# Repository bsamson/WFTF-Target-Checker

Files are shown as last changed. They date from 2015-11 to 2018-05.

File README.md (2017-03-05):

# WFTF-Target-Checker
World Field Target Federation target checking device, plans source code and instructions for manufacture and assembly.

## Printing
There are 8 parts that need to be printed, the STL files can be found in the STL directory.
All dimentions are in mm and the parts are oriented so that no support structures are required.

For best results the parts should be printed in PLA/PHA filament (ColorFabb recommended)
The Left and Right hand Cylinder parts may be prone to some curling on the edges and as a result it is recommended that they are printed individually.

### Suggested printer settings
- Layer height : **0.12 mm**
- Nozzle size : **0.4 mm**
- Print speed : **50 mm/s**
- Fill Density : **25%**

## Assembly Instructions

### Non-Printed parts required :
- 4mm Steel Bar 140mm long
- M3 Nyloc nuts X 8
- M3 x 30mm Cap Head Bolts X 8
- Small spring - 10mm x 5mm
- Main spring 
  - 12.7mm OD
  - 1.25mm Wire
  - Stainless steel
  - 140mm long
  - rated at around 4Nm per cm of compression
  
Note:  This is the spring supplier on eBay that I have used to make the official WFTF checkers :
http://www.ebay.co.uk/itm/12-7mm-OD-13mm-Stainless-Carbon-steel-Compression-spring-up-to-600mm-long-/231995371162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

### Assembly diagrams :
- [Step 1.pdf](Assembly Instructions/Step 1.PDF)
- [Step 2.pdf](Assembly Instructions/Step 2.PDF)
- [Step 3.pdf](Assembly Instructions/Step 3.PDF)
- [Step 4.pdf](Assembly Instructions/Step 4.PDF)
- [Step 5.pdf](Assembly Instructions/Step 5.PDF)
- [Step 6.pdf](Assembly Instructions/Step 6.PDF)

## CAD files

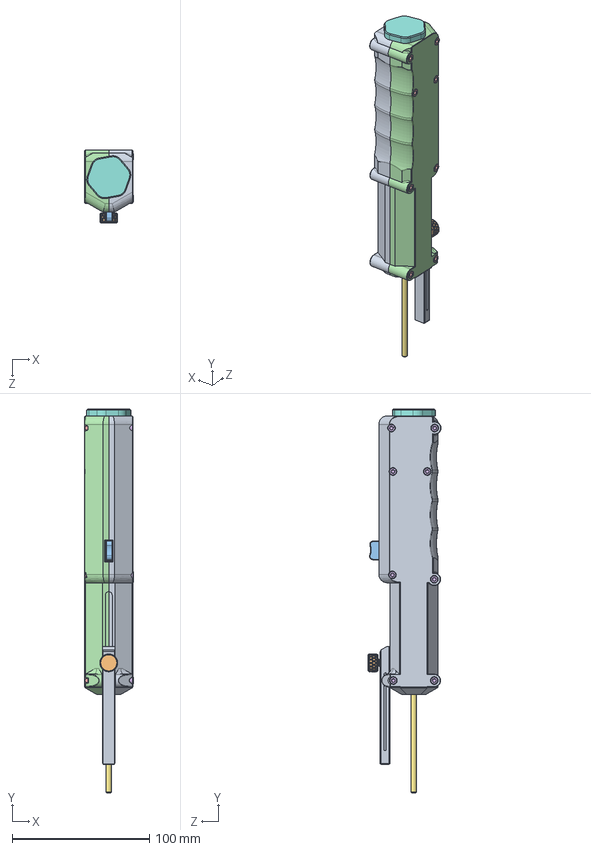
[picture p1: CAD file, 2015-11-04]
Solidworks/Assemblies/Full Assembly.SLDASM
35.3 x 279.8 x 53.2 mm
Cylinder Left Side
Sear Pin
Trigger Sear
Sear return spring
Piston Body
Piston End
Probe
Cylinder End
Depth Gauge
Depth Gauge Screw
Main Spring
Cylinder Right Side
prevailing torque hex nut_am x 8
socket head cap screw_am x 8

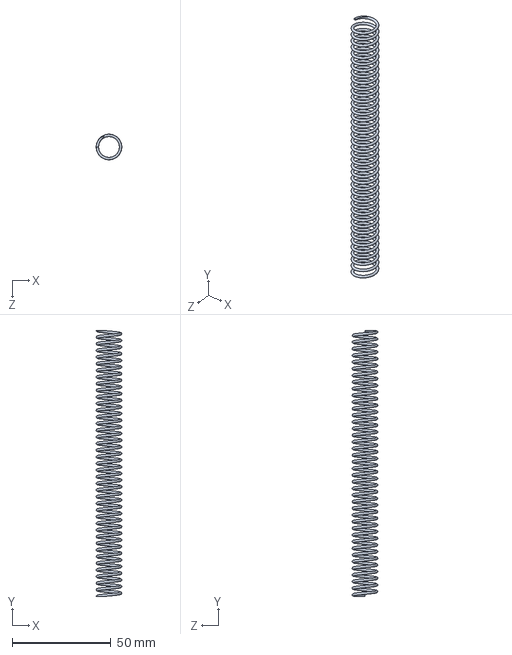
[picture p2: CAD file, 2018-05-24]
Solidworks/Parts/Main Spring.SLDPRT
13.0 x 134.4 x 13.0 mm

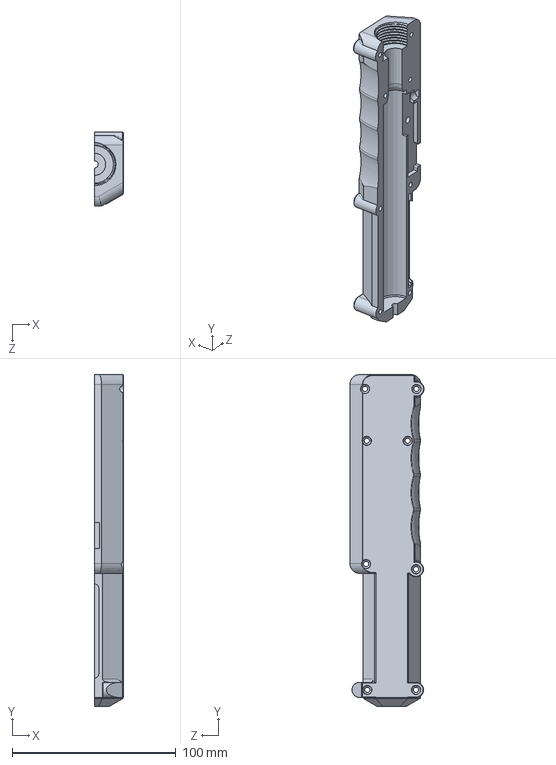
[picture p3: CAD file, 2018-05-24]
Solidworks/Parts/Cylinder Left Side.sldprt
17.5 x 203.0 x 45.3 mm

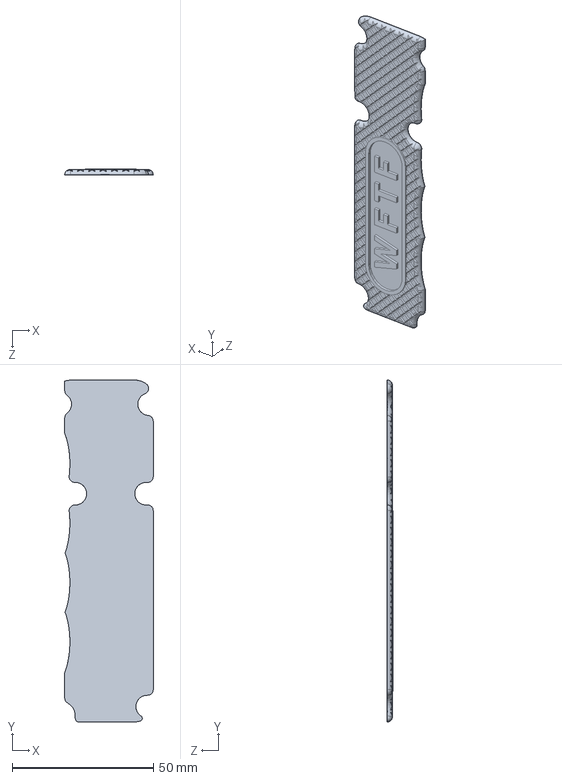
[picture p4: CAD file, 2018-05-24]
Solidworks/Parts/Extras/WFTF Handle LH.sldprt
31.4 x 121.1 x 2.30 mm

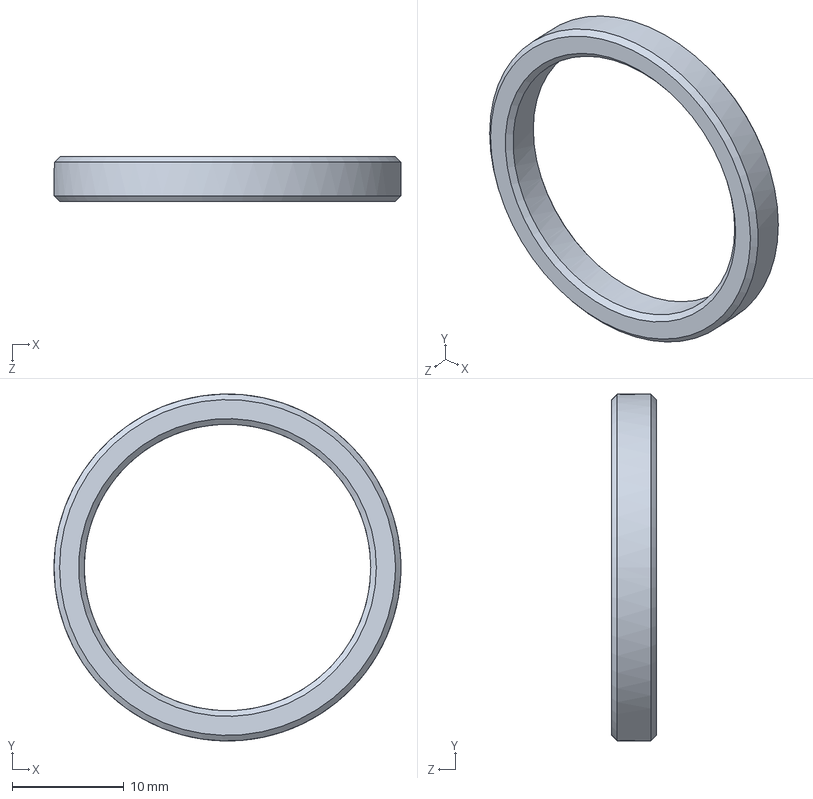
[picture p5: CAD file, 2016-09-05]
Solidworks/Parts/Power Spacers/2_6mm Spacer.SLDPRT
31.0 x 31.0 x 4.00 mm

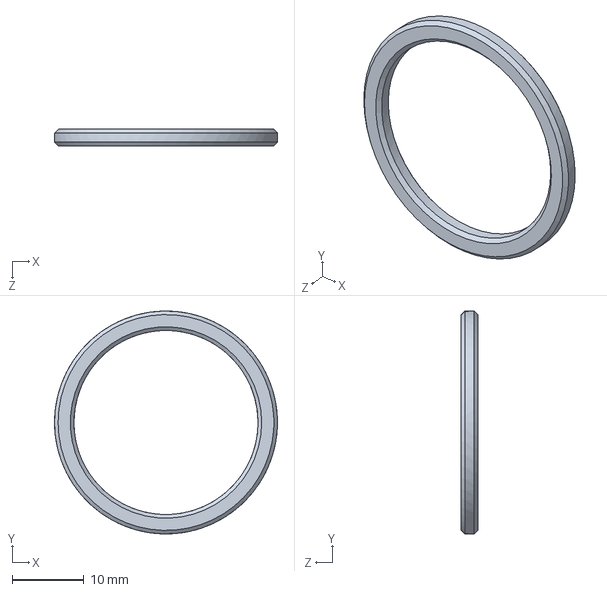
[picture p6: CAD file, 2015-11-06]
Solidworks/Parts/Power Spacers/2_3mm Spacer.SLDPRT
31.0 x 31.0 x 2.30 mm

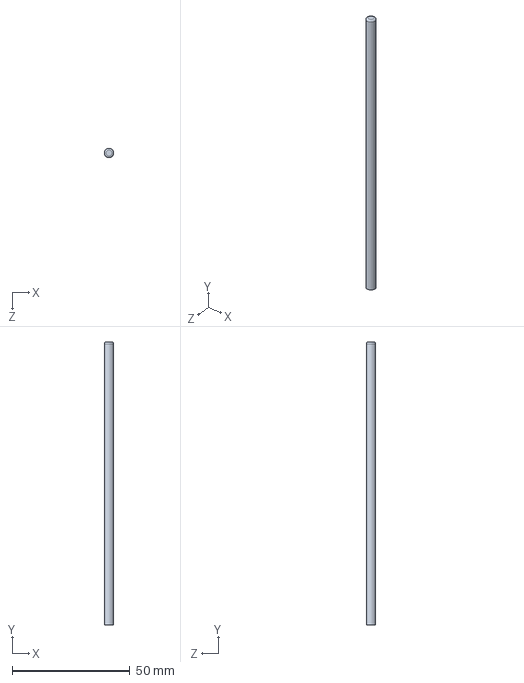
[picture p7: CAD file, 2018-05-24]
Solidworks/Parts/Probe.SLDPRT
4.00 x 120.0 x 4.00 mm

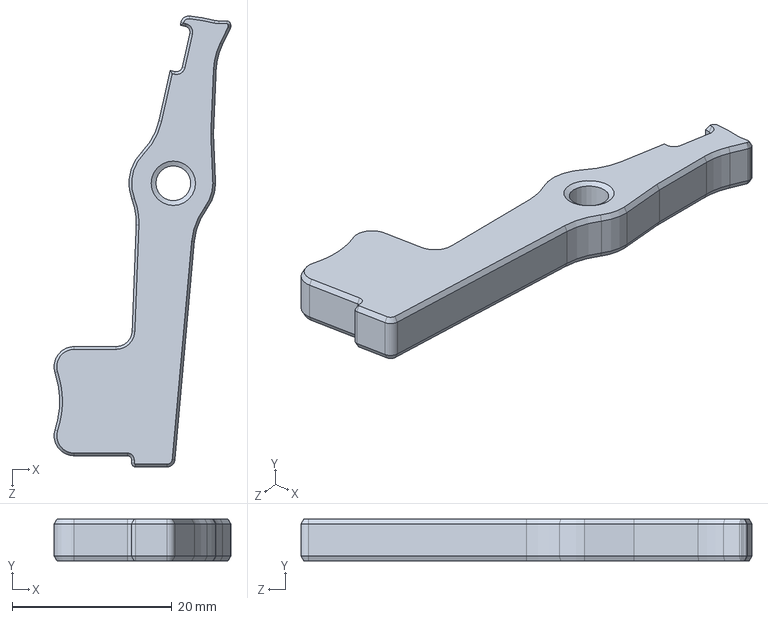
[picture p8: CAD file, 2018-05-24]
Solidworks/Parts/Trigger Sear.SLDPRT
22.1 x 5.25 x 56.4 mm

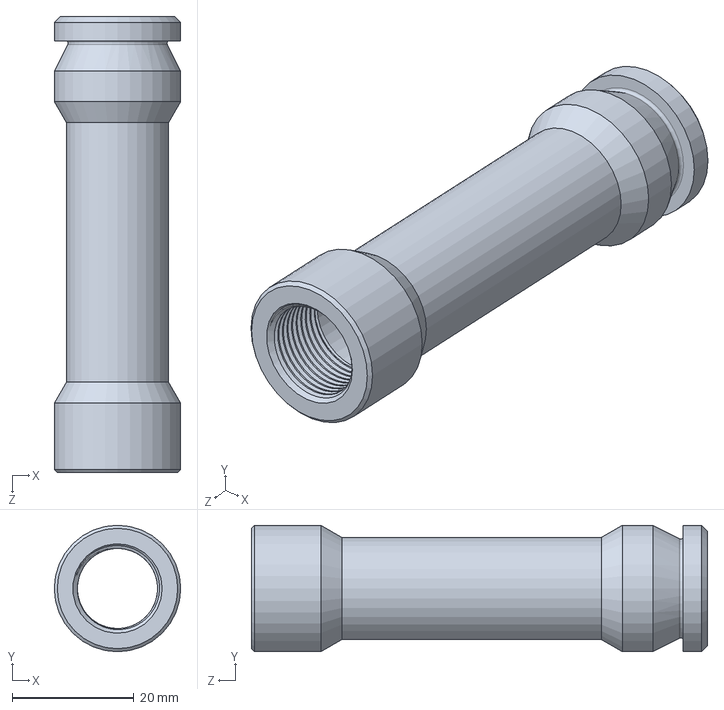
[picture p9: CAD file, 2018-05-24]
Solidworks/Parts/Piston Body.SLDPRT
20.8 x 20.8 x 75.0 mm

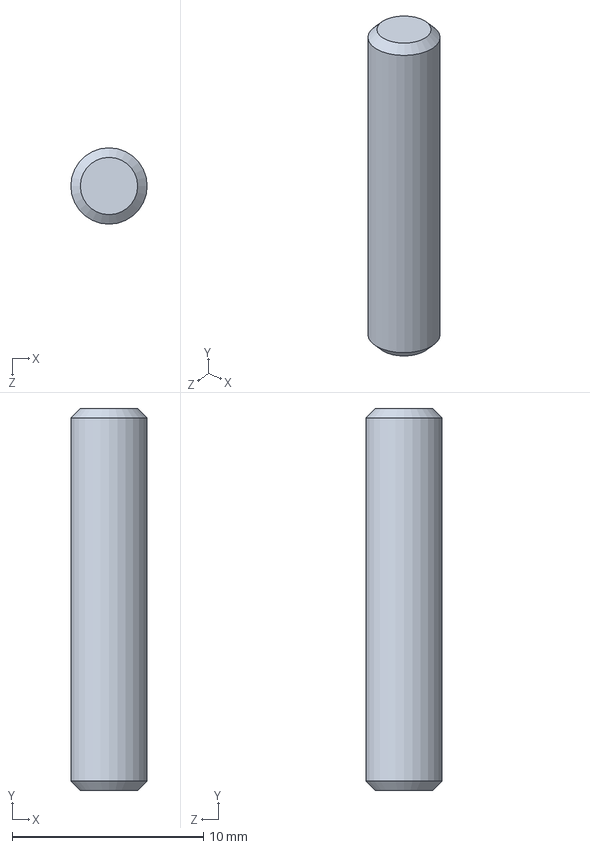
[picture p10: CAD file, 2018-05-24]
Solidworks/Parts/Sear Pin.SLDPRT
4.00 x 20.0 x 4.00 mm

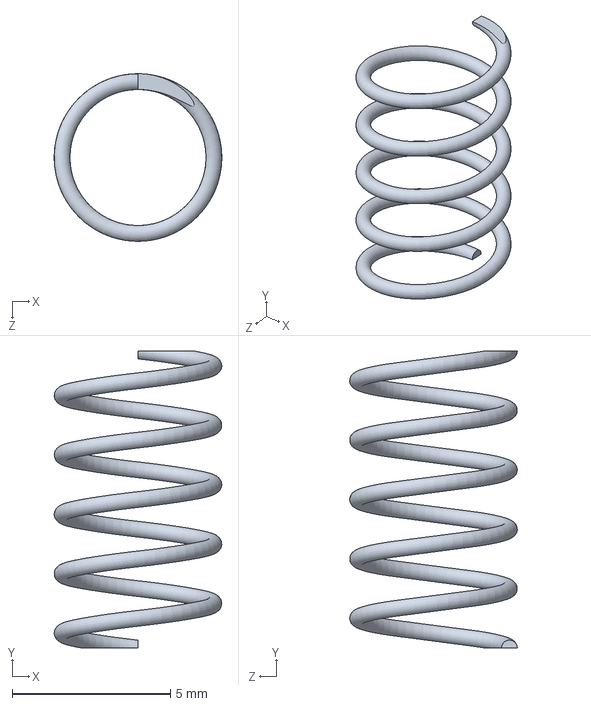
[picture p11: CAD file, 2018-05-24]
Solidworks/Parts/Sear return spring.SLDPRT
5.30 x 9.39 x 5.30 mm

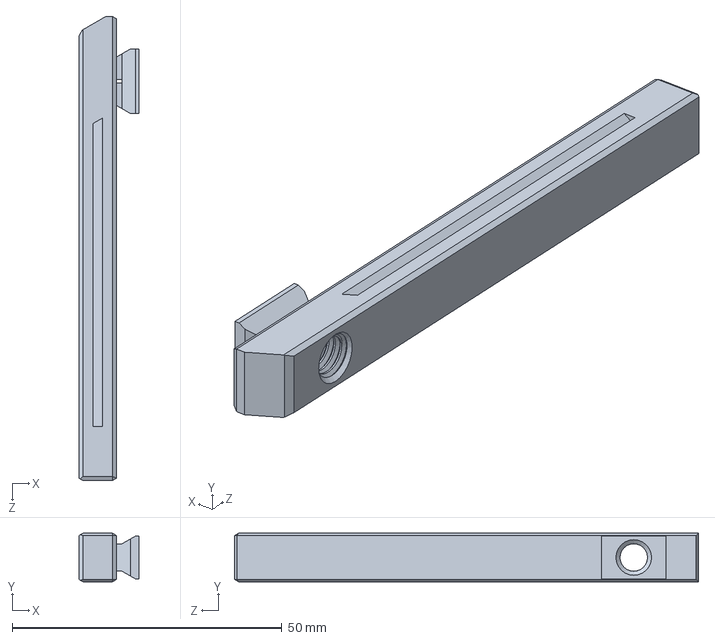
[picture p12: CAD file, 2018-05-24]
Solidworks/Parts/Depth Gauge.SLDPRT
11.2 x 9.00 x 86.0 mm

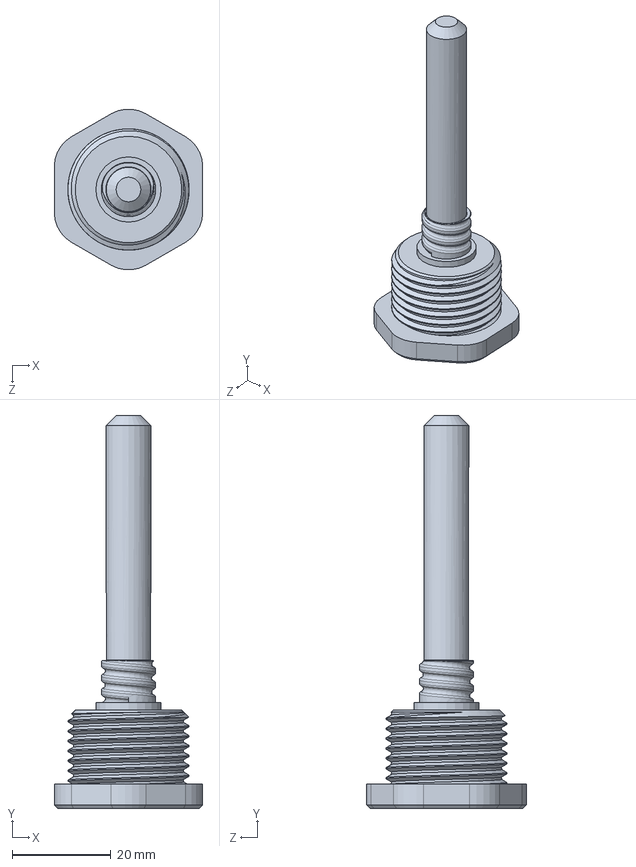
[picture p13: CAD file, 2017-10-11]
Solidworks/Parts/Cylinder End.SLDPRT
30.0 x 79.4 x 32.4 mm

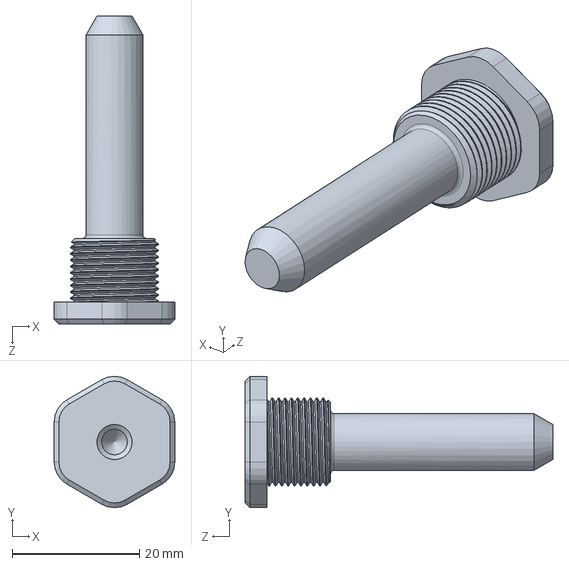
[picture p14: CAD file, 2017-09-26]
Solidworks/Parts/Piston End.SLDPRT
19.0 x 20.7 x 48.5 mm

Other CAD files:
STL/Power Spacers/4mm Spacer.STL
Solidworks/Parts/Extras/WFTF Handle RH.sldprt
Solidworks/Parts/Cylinder Right Side.sldprt
Solidworks/Parts/Cylinder.SLDPRT
STL/Cylinder End.STL
STL/Cylinder Left Side.STL
STL/Cylinder Right Side.STL
STL/Depth Gauge Screw.STL
STL/Depth Gauge.STL
STL/Extras/WFTF Handle LH.STL
STL/Extras/WFTF Handle RH.STL
STL/Piston Body.STL
STL/Piston End.STL
STL/Power Spacers/2_3mm Spacer.STL
STL/Power Spacers/2_6mm Spacer.STL
STL/Trigger Sear.STL
Solidworks/Drawings/Assembly Instruction Drawings/Step 1.SLDDRW
Solidworks/Drawings/Assembly Instruction Drawings/Step 2.SLDDRW
Solidworks/Drawings/Assembly Instruction Drawings/Step 3.SLDDRW
Solidworks/Drawings/Assembly Instruction Drawings/Step 4.SLDDRW
Solidworks/Drawings/Assembly Instruction Drawings/Step 5.SLDDRW
Solidworks/Drawings/Assembly Instruction Drawings/Step 6.SLDDRW
Solidworks/Drawings/Full Assembly.SLDDRW
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

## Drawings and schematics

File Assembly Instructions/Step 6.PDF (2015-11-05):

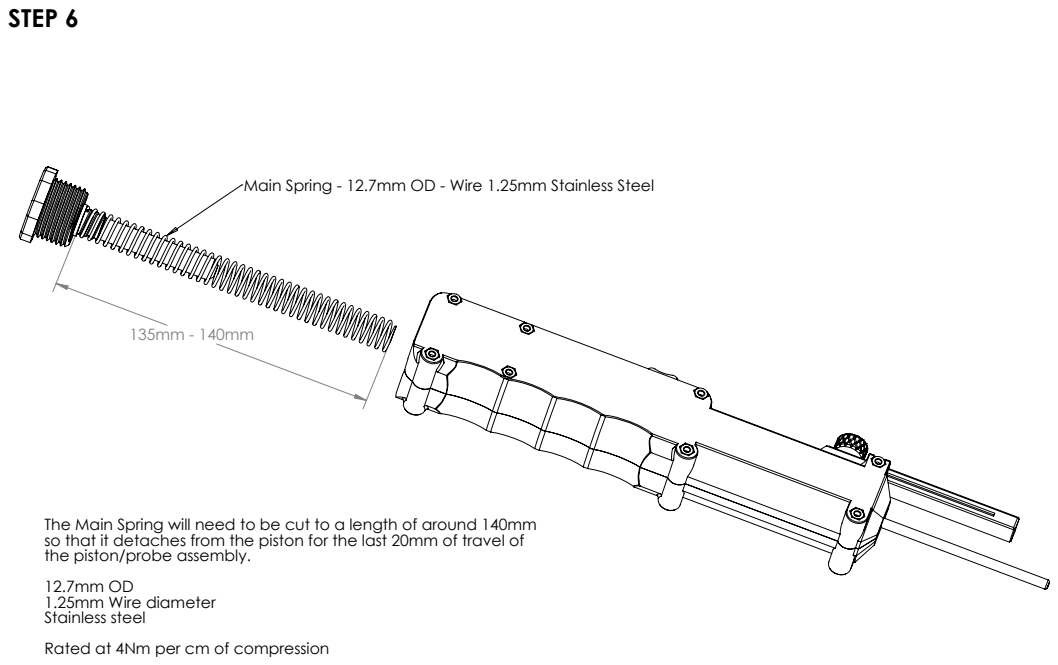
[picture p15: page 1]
STEP 6

Main Spring - 12.7mm OD - Wire 1.25mm Stainless Steel

The Main Spring will need to be cut to a length of around 140mm
so that it detaches from the piston for the last 20mm of travel of
the piston/probe assembly.
1.25mm Wire diameter
Stainless steel
Rated at 4Nm per cm of compression

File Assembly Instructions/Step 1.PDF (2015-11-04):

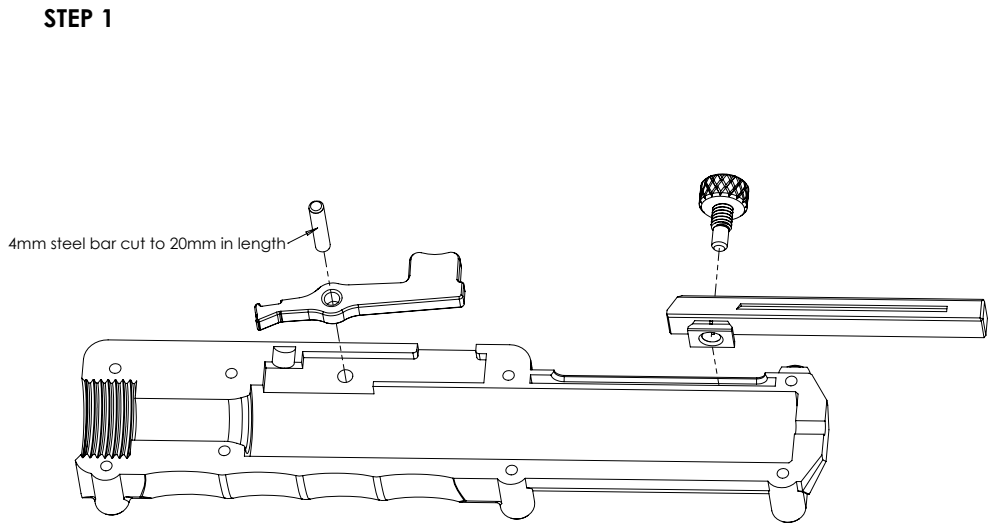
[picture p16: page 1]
STEP 1

4mm steel bar cut to 20mm in length

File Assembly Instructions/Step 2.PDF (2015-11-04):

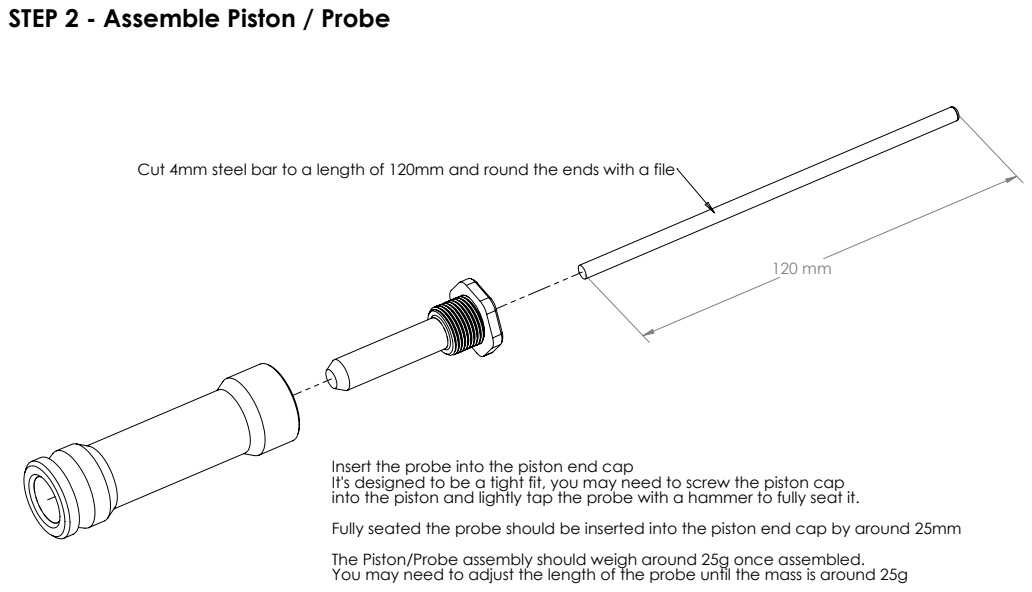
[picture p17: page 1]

STEP 2 - Assemble Piston / Probe

Cut 4mm steel bar to a length of 120mm and round the ends with a file

Insert the probe into the piston end cap
It's designed to be a tight fit, you may need to screw the piston cap
into the piston and lightly tap the probe with a hammer to fully seat it.
Fully seated the probe should be inserted into the piston end cap by around 25mm
The Piston/Probe assembly should weigh around 25g once assembled.
You may need to adjust the length of the probe until the mass is around 25g

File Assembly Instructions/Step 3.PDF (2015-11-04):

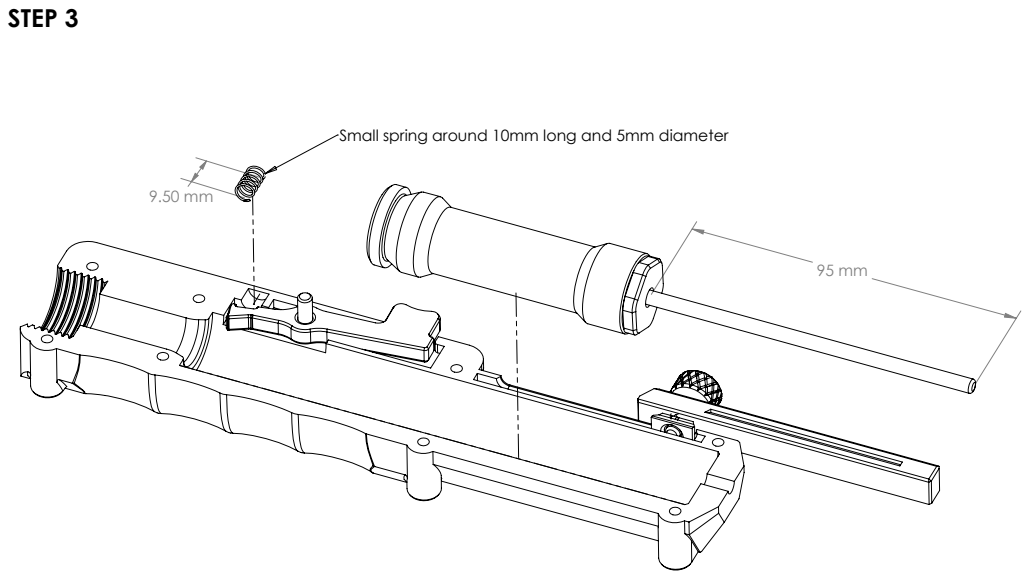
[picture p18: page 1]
STEP 3

Small spring around 10mm long and 5mm diameter

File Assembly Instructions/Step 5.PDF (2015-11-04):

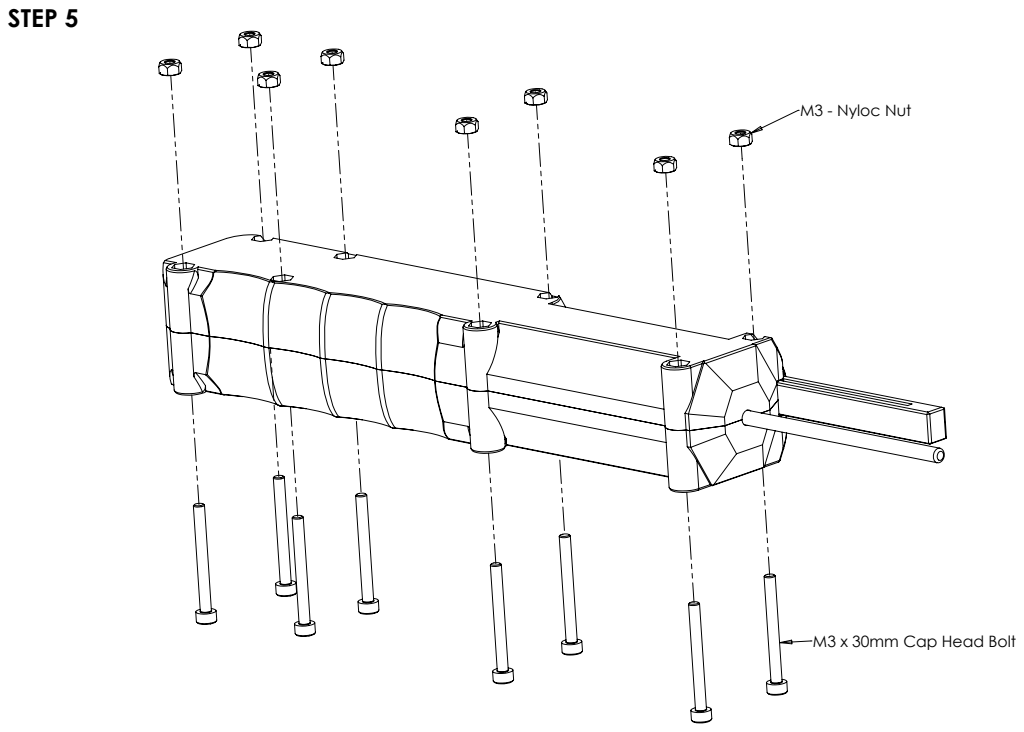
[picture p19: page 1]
M3 - Nyloc Nut; STEP 5

M3 x 30mm Cap Head Bolt

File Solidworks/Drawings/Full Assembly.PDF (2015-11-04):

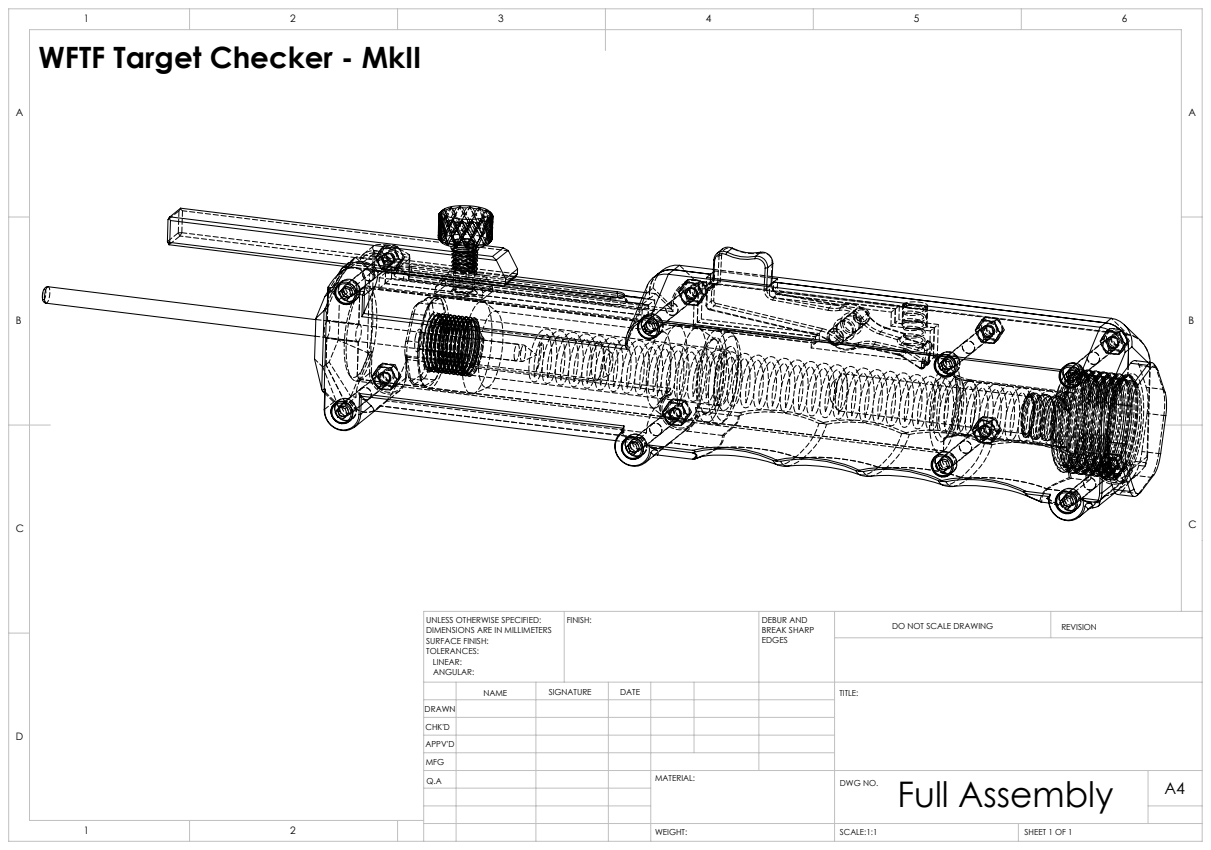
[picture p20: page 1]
FINISH:; DEBUR AND; BREAK SHARP; DO NOT SCALE DRAWING; REVISION; SCALE:1:1; SHEET 1 OF 1

WFTF Target Checker - MkII

UNLESS OTHERWISE SPECIFIED:
DIMENSIONS ARE IN MILLIMETERS
SURFACE FINISH:
TOLERANCES:
LINEAR:
ANGULAR:

NAME | SIGNATURE | DATE | | | | TITLE:

DRAWN
CHK'D
APPV'D
MFG
Q.A | | | | MATERIAL: | Full Assembly DWG NO. | A4

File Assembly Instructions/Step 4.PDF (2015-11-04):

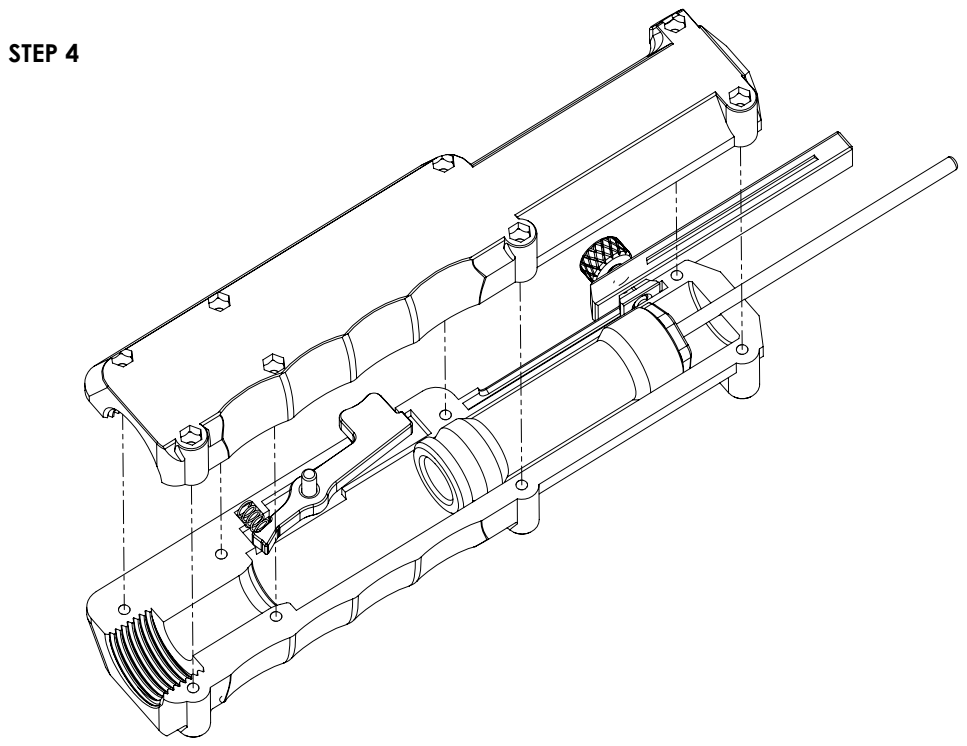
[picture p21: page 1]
STEP 4

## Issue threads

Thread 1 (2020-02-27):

Assembly instructions call for Cap Head Bolts but holes are countersunk

neildarlow, 2020-02-27:
Looking at building one of these for my club and noticed, as the title says, that the "Cylinder Left Side" has countersunk holes for Cap Head Bolts. A parallel sided hole would be better for them.

12345Josparky, 2020-03-11:
There have been many of these printed and they work great. He has given the cad files in with the printable files so anyone can edit it how they like. I have modified some parts on it for my use. This was not an easy project for him to do I am sure. I for one am thankful he spent the time and effort to make it I am sure it took weeks to work out all the bugs. Then for him to offer it up free for use any way you like and add the cad files was awesome. Thanks you so much.

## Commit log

2015-11-04 Initial version
    [Cylinder End.SLDPRT, Cylinder End.STL, Cylinder Left Side.STL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]
2015-11-04 Change orientation of STL files to print without supports
    [Cylinder End.STL, Cylinder Left Side.STL, Cylinder Right Side.STL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]
2015-11-04 Assembly instruction pdfs added
    [Step 1.SLDDRW, Step 2.SLDDRW, Step 3.SLDDRW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]
2015-11-05 Updated assembly instructions with correct wire diameter
    [Step 6.SLDDRW]
2015-11-06 Included some spacers for setting power
    [2_3mm Spacer.SLDPRT, 2_3mm Spacer.STL, 2_6mm Spacer.SLDPRT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]
2016-09-05 Increase thread clearance on Piston body and include a WFTF handle plate
    [2_6mm Spacer.SLDPRT, Full Assembly.SLDDRW, Piston Body.SLDPRT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]
2016-09-27 Updated assembly and added an extra spacer part
    [4mm Spacer.STL, WFTF Handle LH.STL, WFTF Handle LH.sldprt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]
2017-03-05 Reduced diameter of the piston end part to give more clearance
    [Piston End.SLDPRT, Piston End.STL]
2017-03-05 Reduced some parts to make them less of a tight fit
    [Cylinder End.SLDPRT, Cylinder End.STL, Depth Gauge Screw.SLDPRT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]
2017-03-05 Update to the Readme to include eBay link to spring supplier
2017-03-06 further tweaks to tolerances
    [Cylinder End.SLDPRT, Cylinder End.STL, Piston Body.SLDPRT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]
2017-09-26 increase tolerances on the piston body and end
    [Piston Body.SLDPRT, Piston Body.STL, Piston End.SLDPRT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]
2017-10-11 increase tolerances to make parts fit better on lower spec printers
    [Cylinder End.SLDPRT, Cylinder End.STL, Depth Gauge Screw.SLDPRT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]
2018-05-24 some design tweaks
    [Cylinder Left Side.sldprt, Cylinder Right Side.sldprt, Depth Gauge Screw.SLDPRT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]
